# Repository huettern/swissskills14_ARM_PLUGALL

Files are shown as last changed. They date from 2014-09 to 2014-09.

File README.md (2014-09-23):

swissskills14_ARM_PLUGALL
=========================

I participated to the Swiss Skills 2014. One task was to design specific software. I prepared myself with a custom microcontroller board and some libraries for faster workflow. 
I'm sharing my sources here for others to have some open libraries for the STM32f3 family. The code is not very good commented, so if you have questions or troubles, feel free to contact me.

Directory Hardware
------------------

This directory contains the Altium project and manufature data for the PLUGALL ARM board.

Directory Software
------------------

This directory contains the template code and my self-written libraries to handle the PLUGALL bus communication.

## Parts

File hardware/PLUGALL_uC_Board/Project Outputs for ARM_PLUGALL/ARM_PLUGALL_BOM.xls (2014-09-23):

Comment | Designator | Quantity | Value | Footprint | MM Pnum
C | C1, C2, C5, C7, C8, C11, C12, C13, C14, C15, C16 | 11 | 100nF | 0805
C | C3, C4, C9 | 3 | 10uF | 0805
C | C6, C10 | 2 | 1uF | 0805
LED | D1 | 1 | BLU | D_0603
LED | D4 | 1 | GRN | D_0603
LED | D5 | 1 | RED | D_0603
R | R1, R4 | 2 | 4k7 | R_0603
R | R2, R5, R6, R7, R8, R9, R10, R11, R12, R13, R14, R15, R16 | 13 | 1k | R_0603
R | R3, R18, R19 | 3 | 100 | R_0603
SW | S1 | 1 | SW | SW_4x4x1.5
STM32F373RBT6 | U1 | 1 | STM32F372RBT6 | STM-LQFP64_V
74LVX3245 | U2, U3 | 2 | 74LVX3245 | TSSOP24
LM3940IMP-3.3 | U4 | 1 | LM3940IMP-3.3 | SOT-223
V_REF | U5 | 1 | LM4050 | SOT-23
SN74LV1T34 | U6, U7, U8 | 3 | SN74LV1T34 | DCK
FDV301N | V1, V2 | 2 | FDV301N | SOT-23
PLUGALL_Bus_Con | X1 | 1 | 2x14 | CON14X2
Socket_2mm | X2, X4 | 2 | Banana_2mm_RED | 2MM_BANANA
Socket_2mm | X3, X5 | 2 | Banana_2mm_BLK | 2MM_BANANA
Header 5H | X6 | 1 | 1X5 | HDR1X5H
SWD | X7 | 1 | 2X5 | 4448.0054
 |  | 55

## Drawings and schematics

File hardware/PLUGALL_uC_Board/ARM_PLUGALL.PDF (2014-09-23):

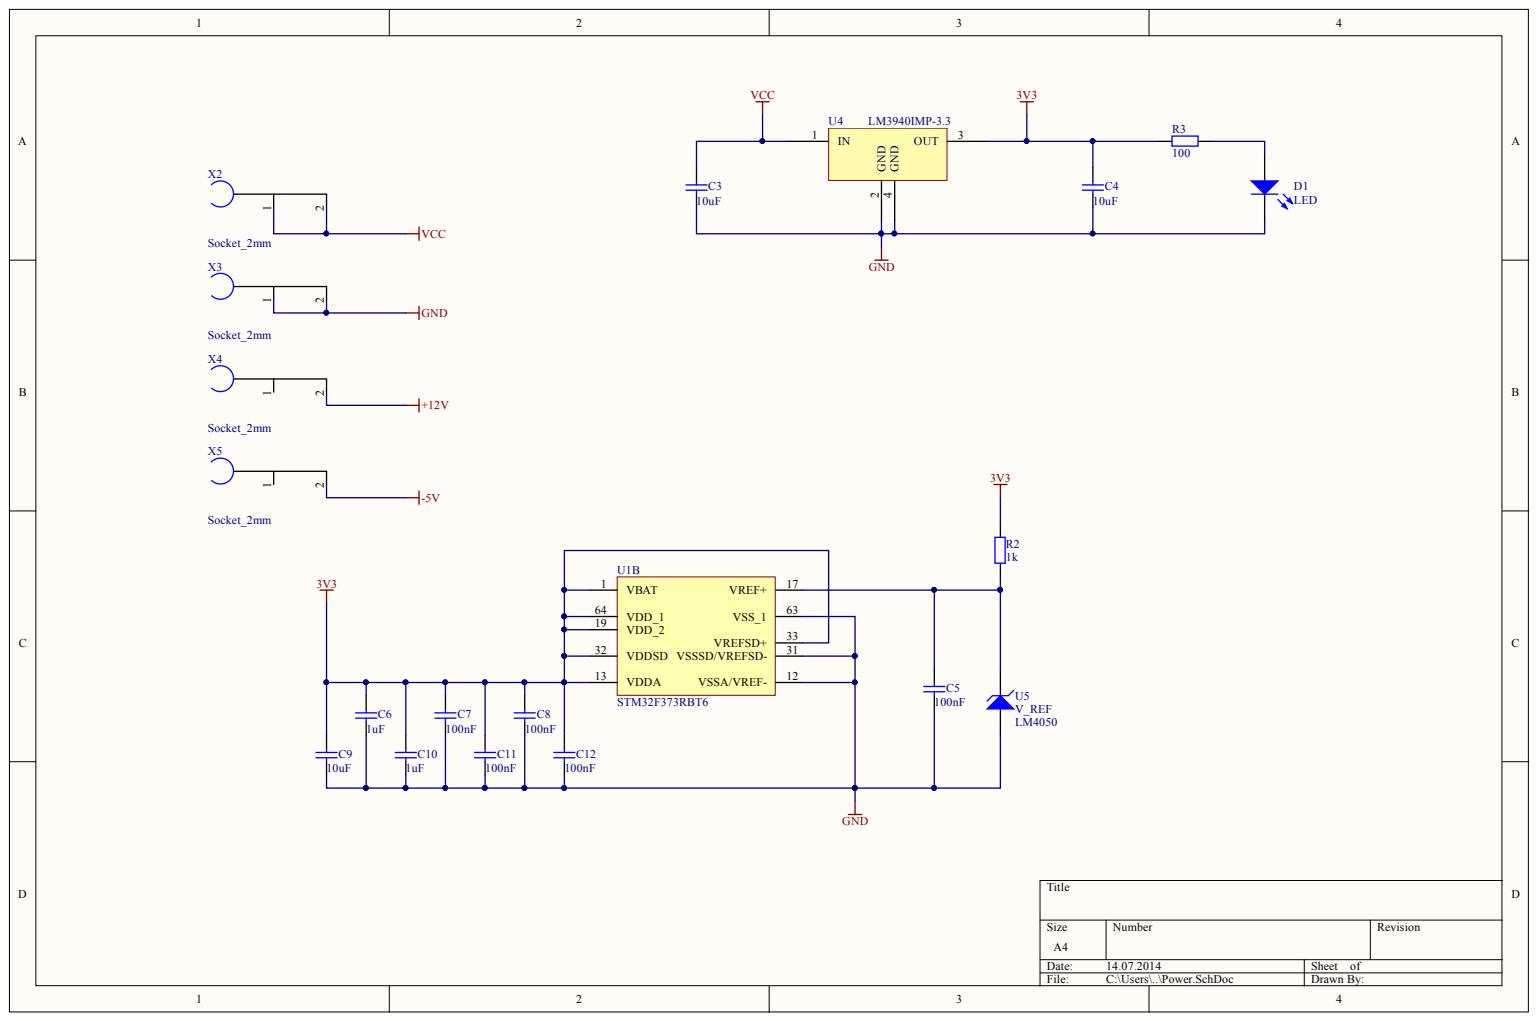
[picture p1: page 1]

6 4 | 6 3
1 9 | 3 3

3 2 | V D DSD VSSSD / VREFSD -V D D A VSSA / VREF- | 3 1

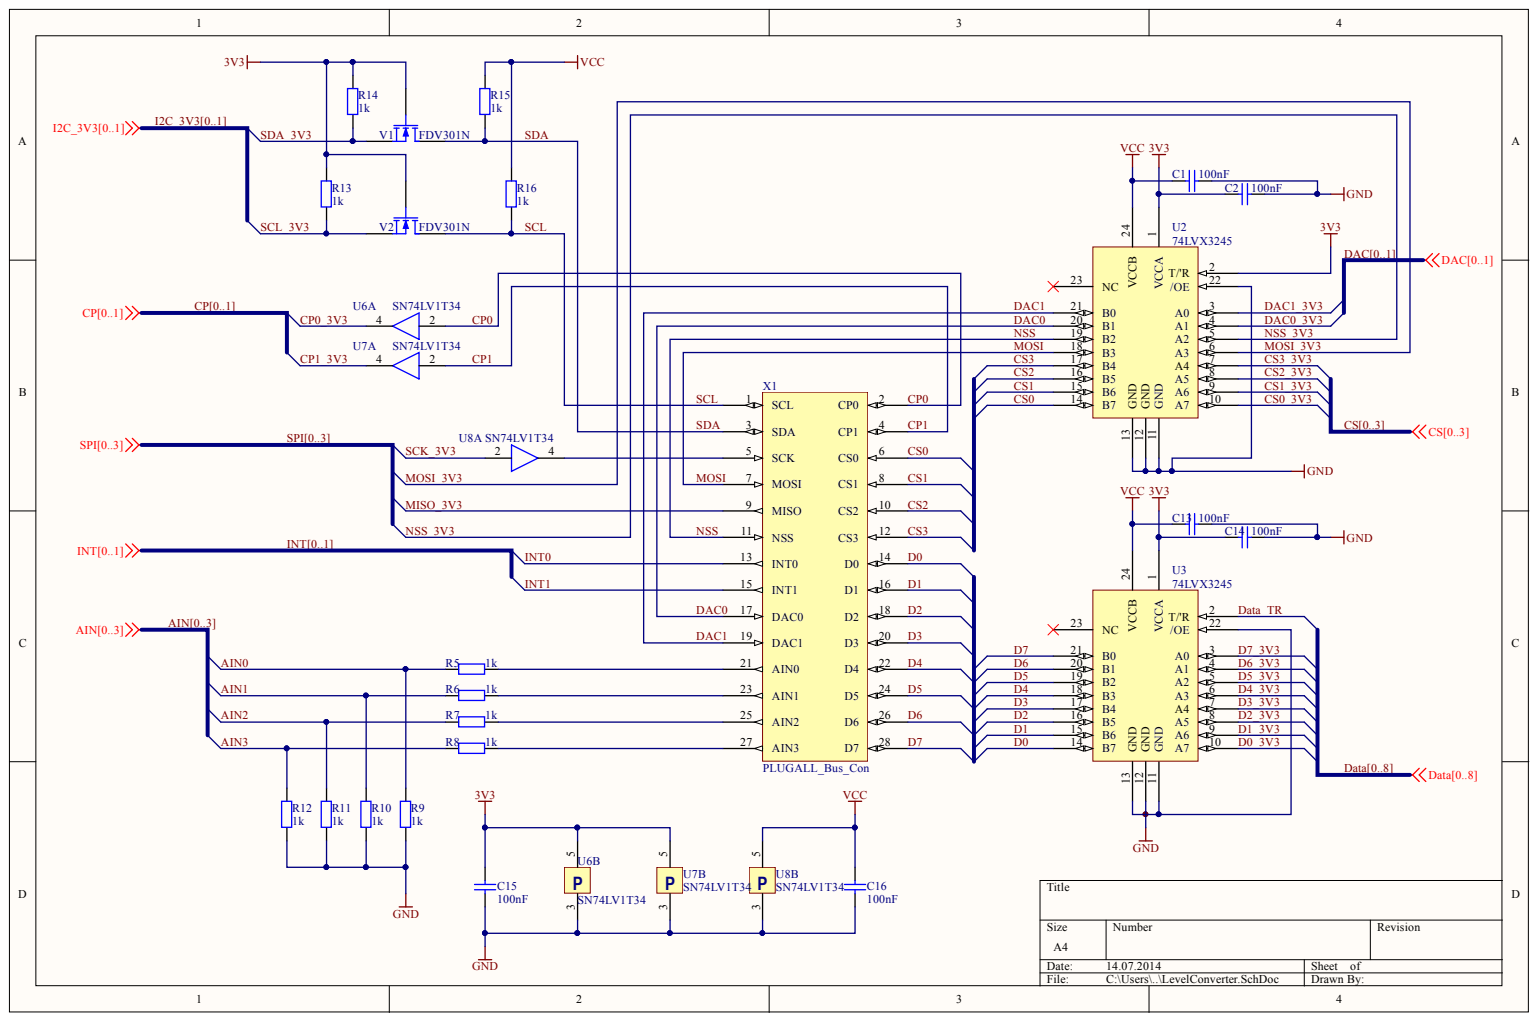
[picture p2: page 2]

MOSI NSS DAC0 DAC1 1 1 | 1 2 CS3

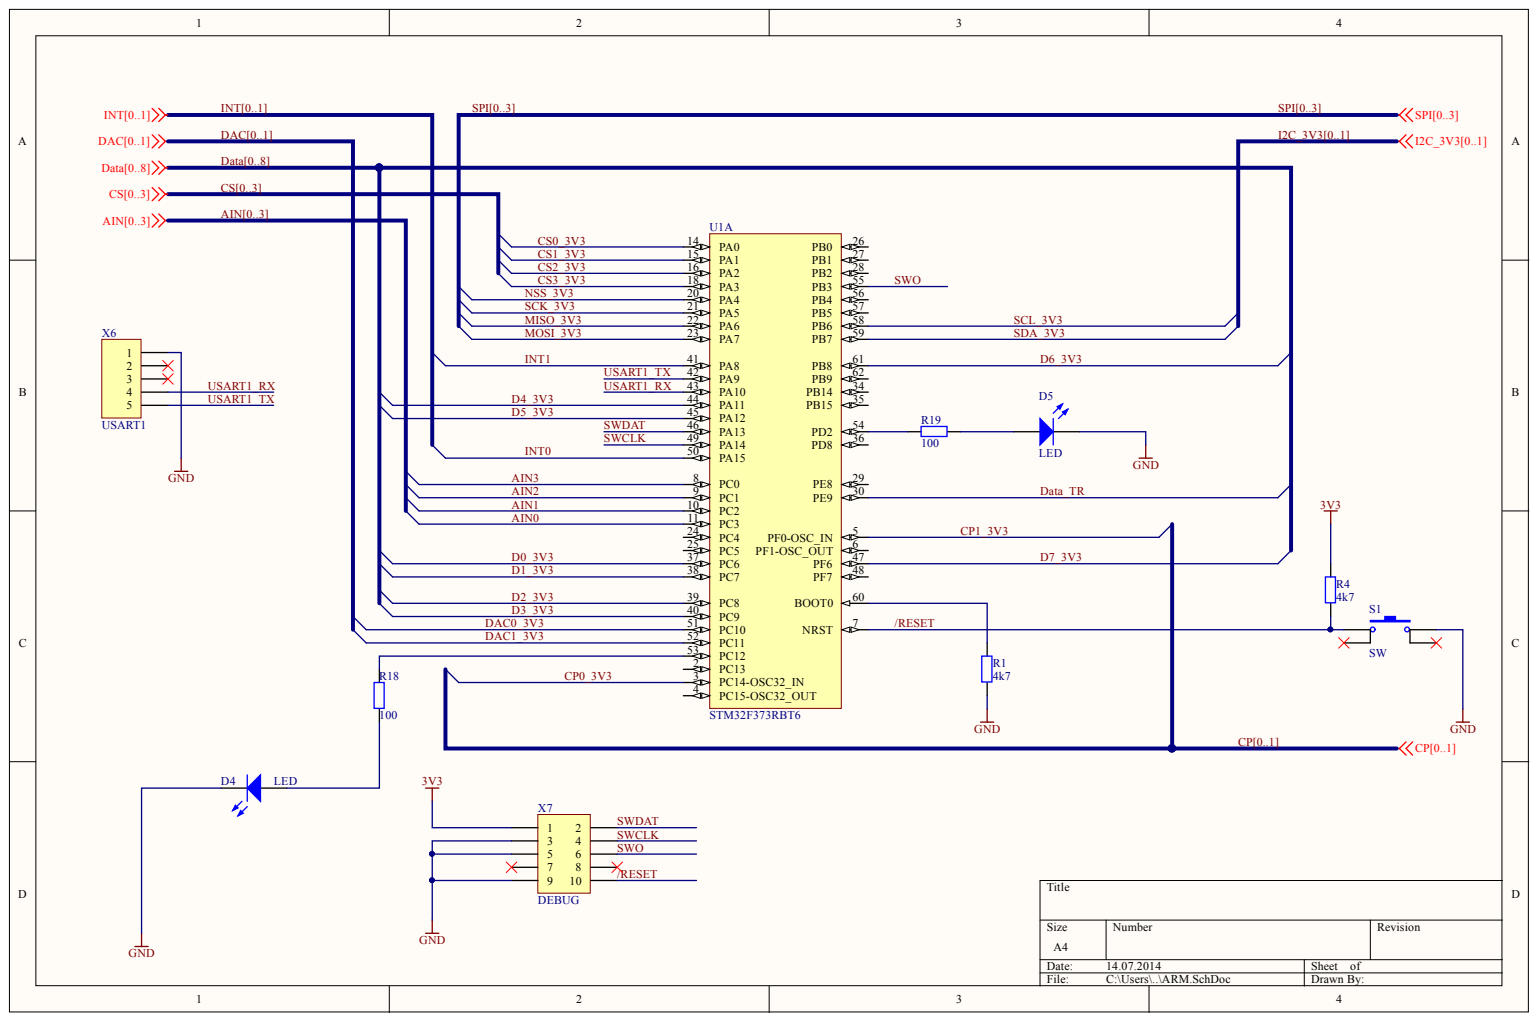
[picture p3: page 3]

AIN[0..3 ]

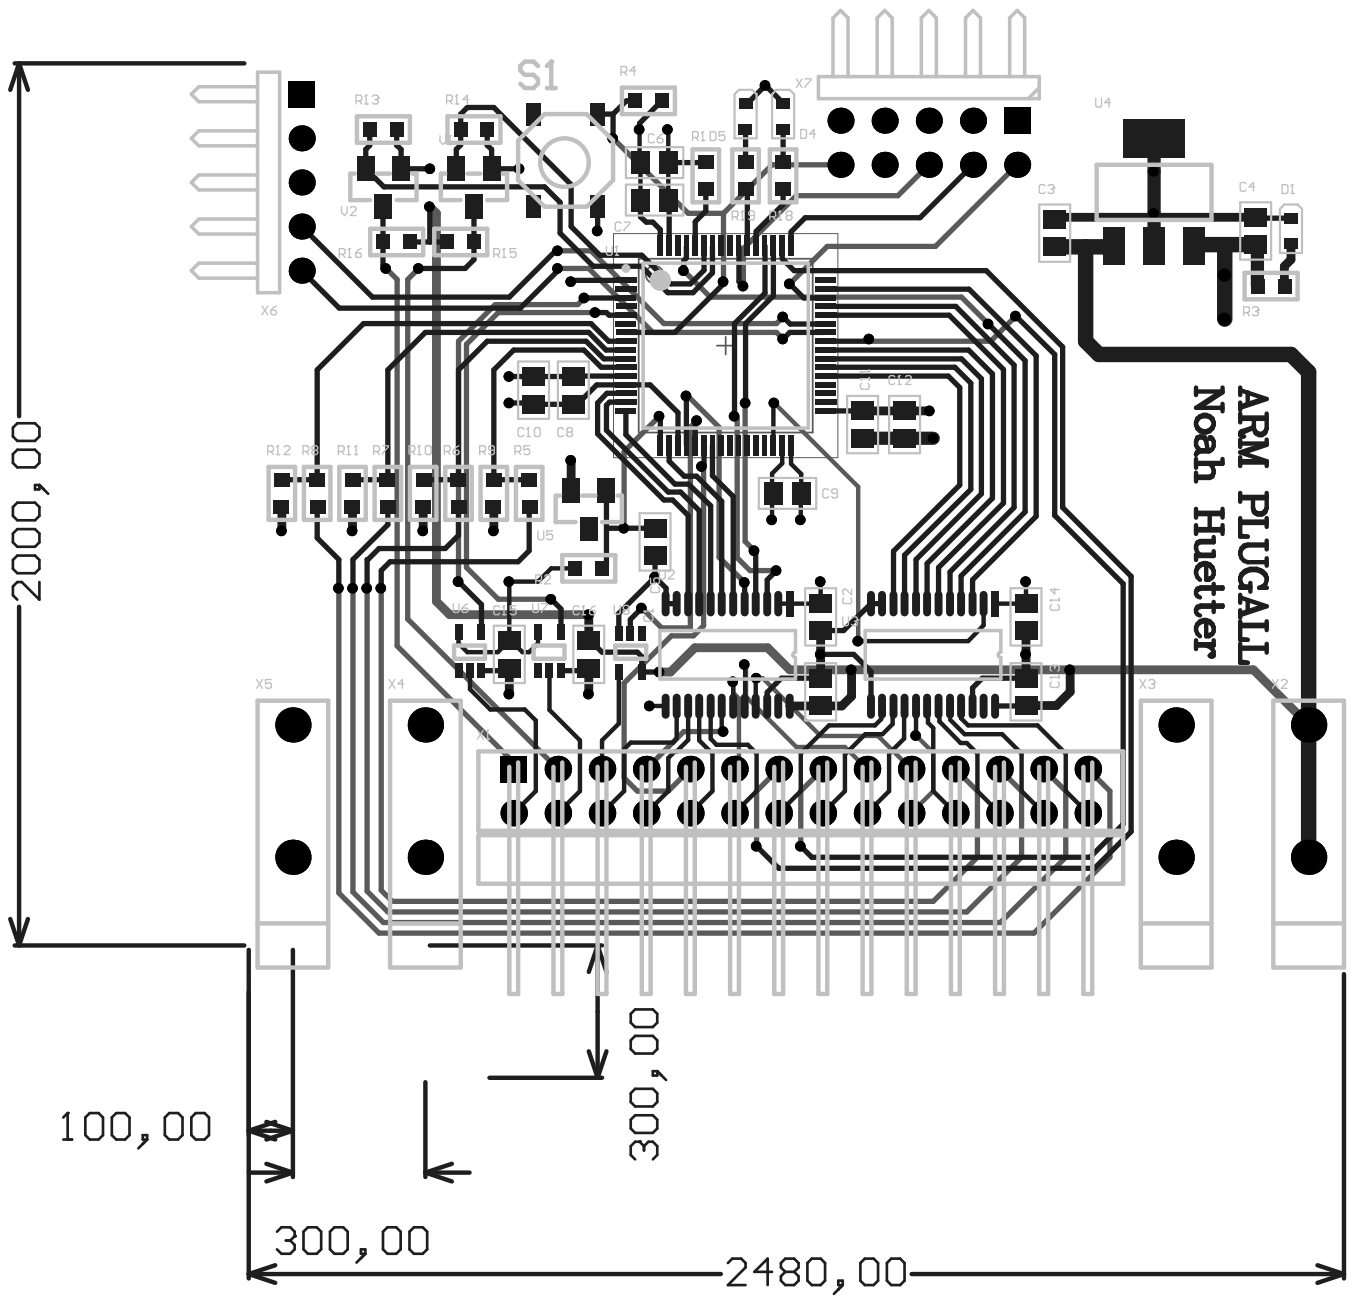
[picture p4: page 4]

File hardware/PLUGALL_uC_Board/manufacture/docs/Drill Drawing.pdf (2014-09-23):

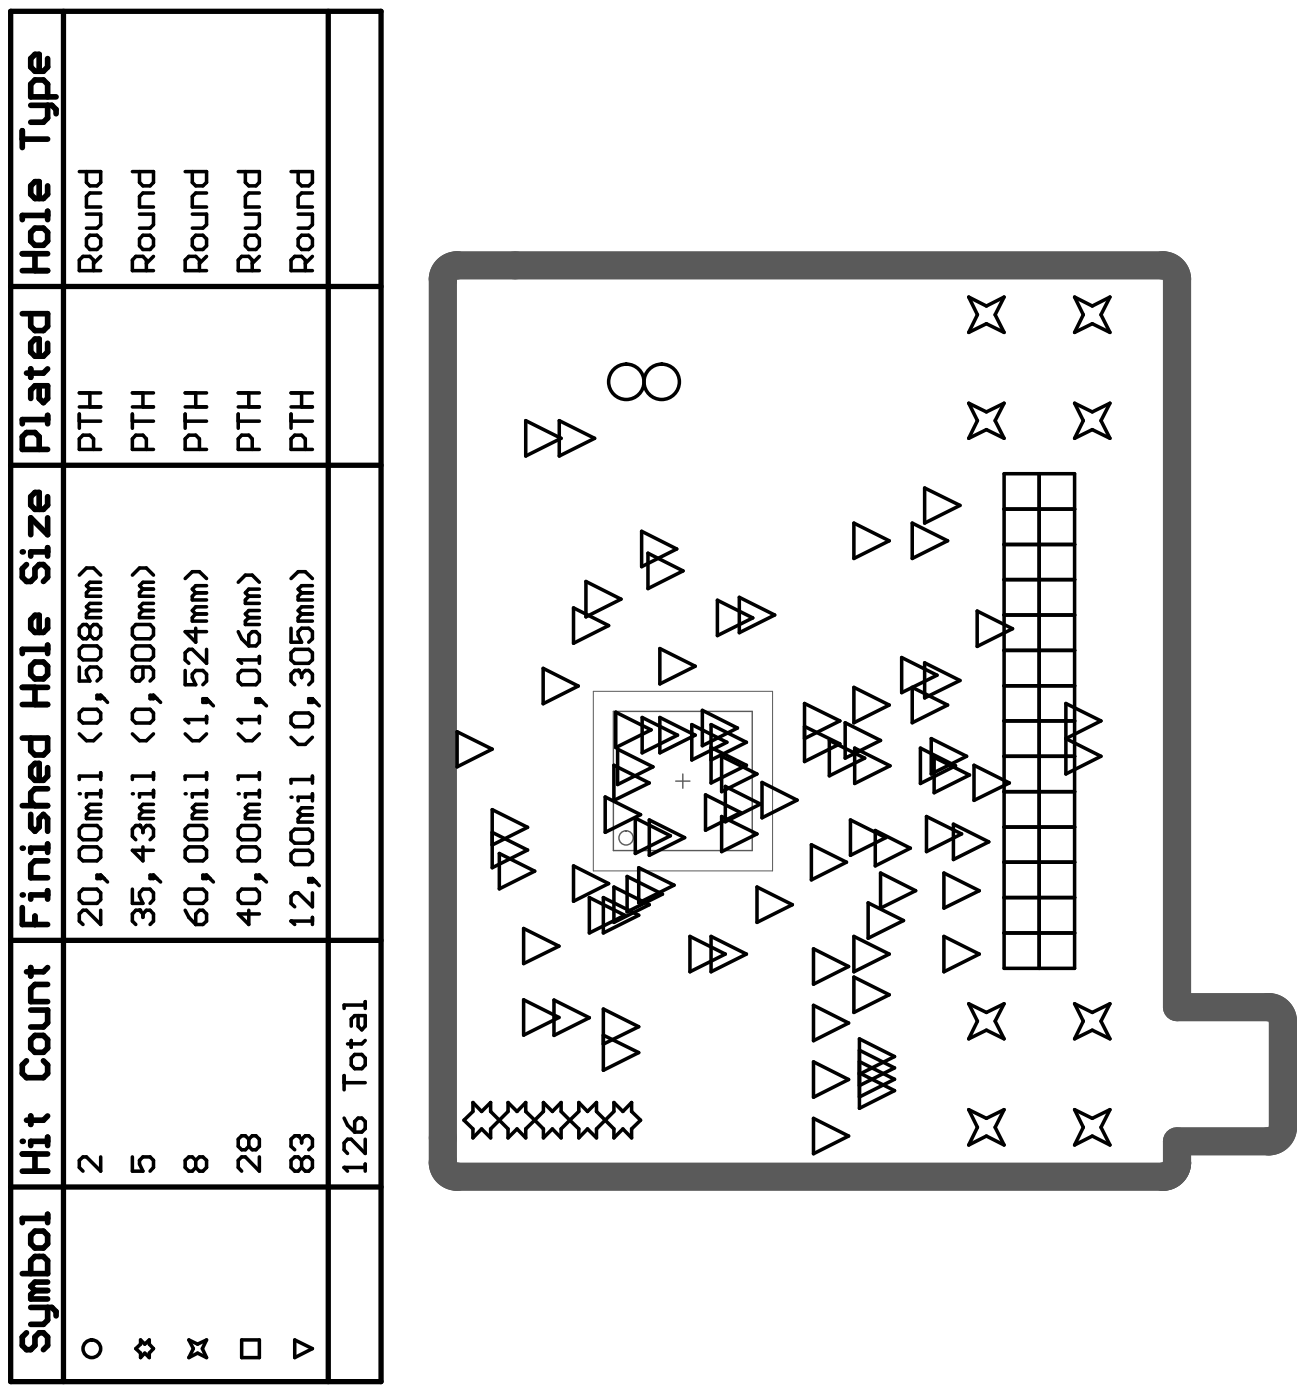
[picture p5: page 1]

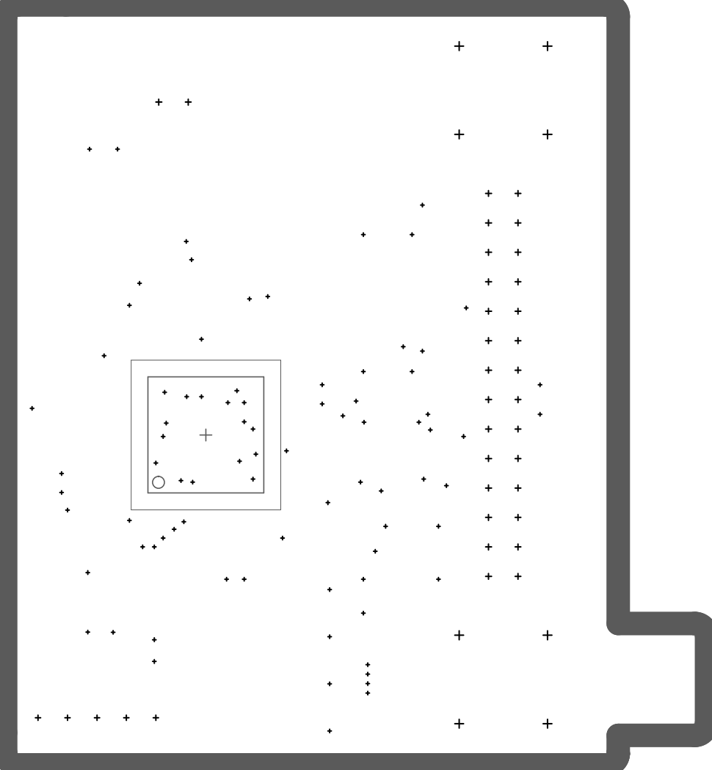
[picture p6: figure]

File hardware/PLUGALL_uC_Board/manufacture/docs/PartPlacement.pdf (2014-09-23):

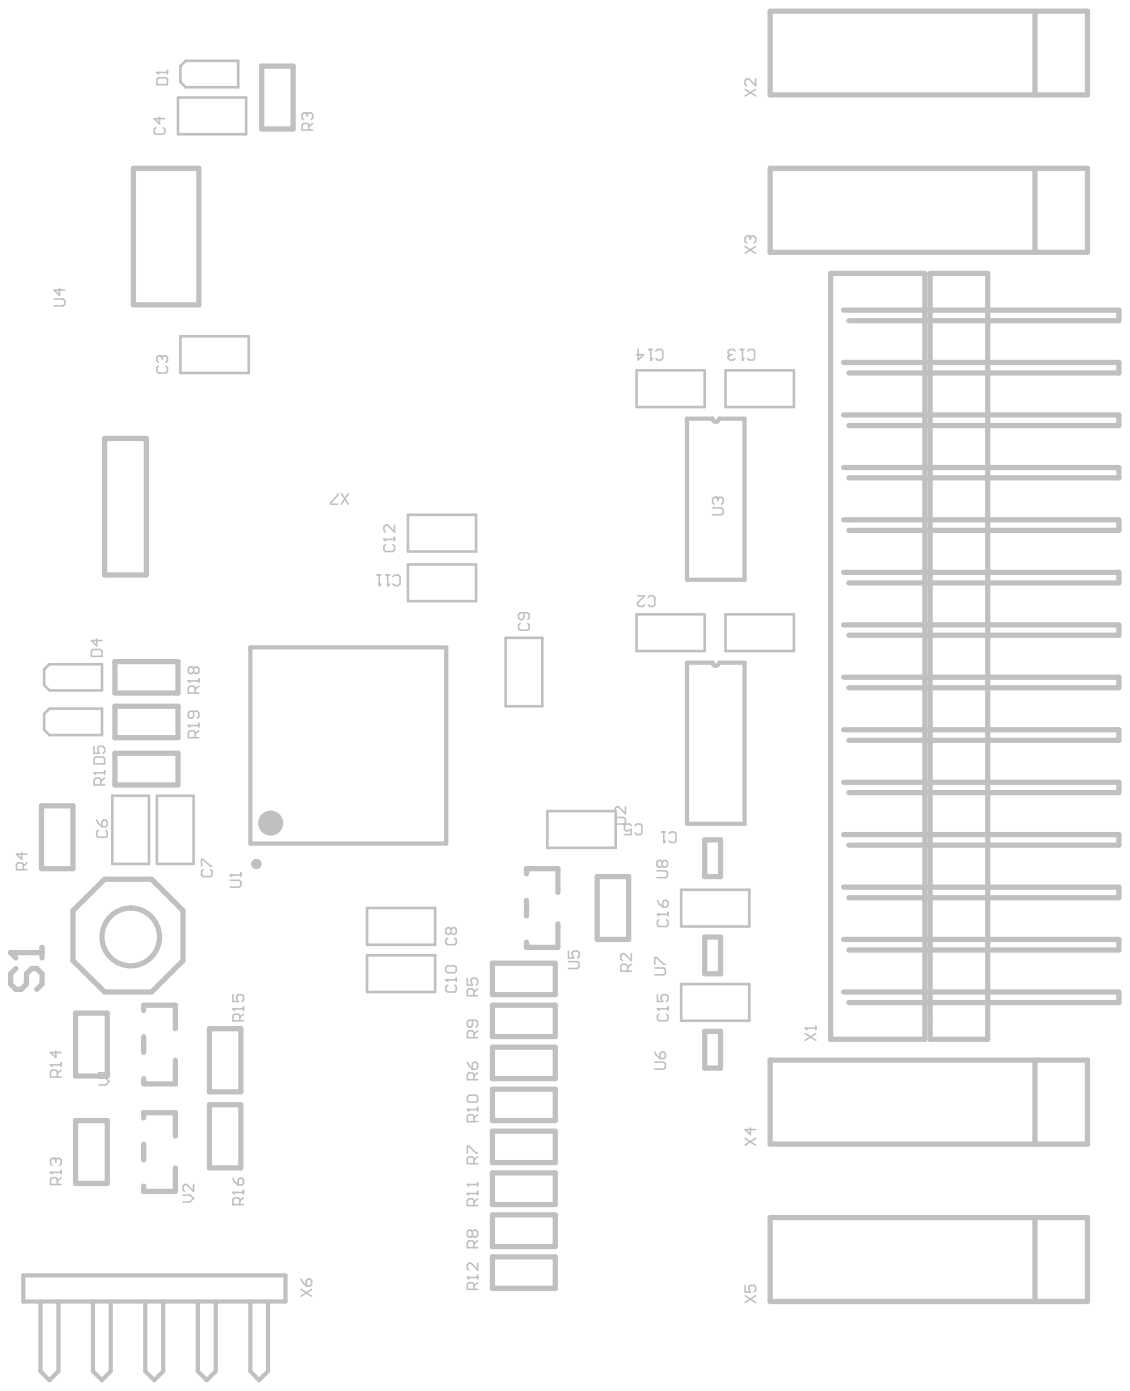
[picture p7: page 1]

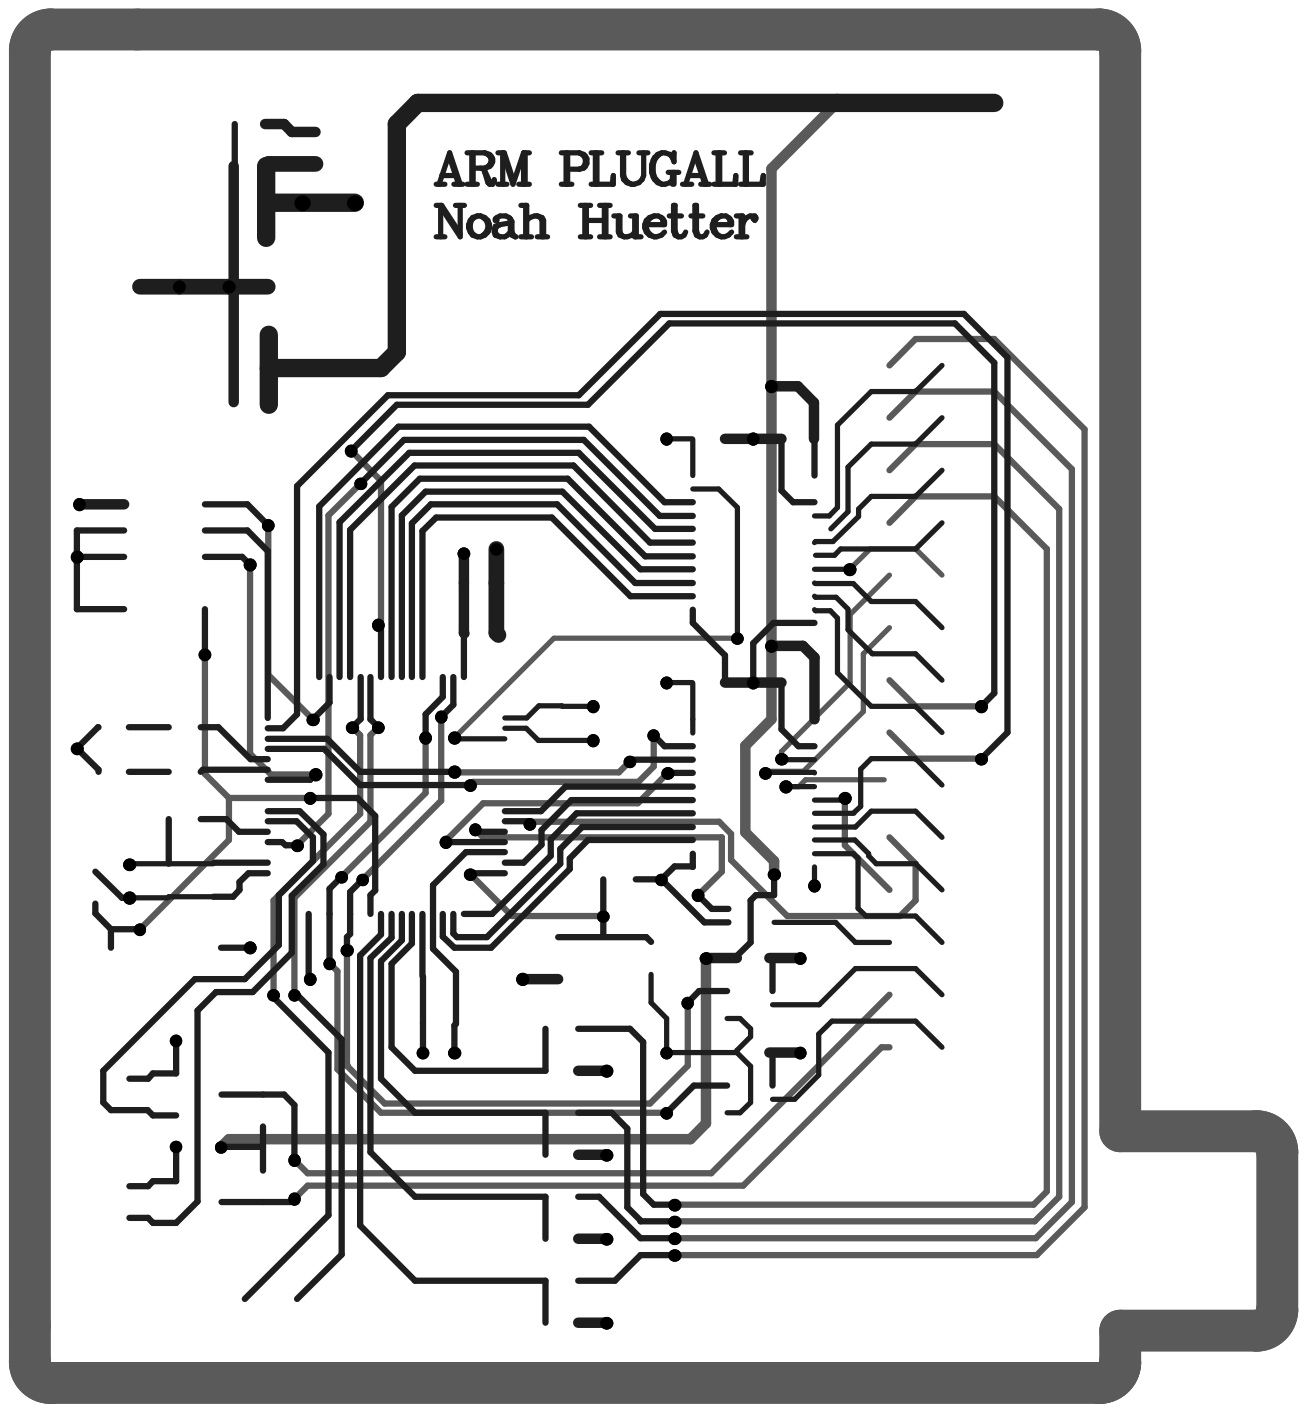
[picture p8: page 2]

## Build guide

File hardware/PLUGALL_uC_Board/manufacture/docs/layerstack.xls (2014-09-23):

Board Stack Report
Stack Up |  |  | Layer Stack
Layer | Board Layer Stack | Board Layer Stack | Name | Material | Thickness | Constant
1 |  |  | Top Paste
2 |  |  | Top Overlay
3 |  |  | Top Solder | Solder Resist | 0,40mil | 3,5
4 |  |  | Top Layer | Copper | 1,40mil
5 |  |  | Dielectric 1 | FR-4 | 10,00mil | 4,2
6 |  |  | GND | Copper | 1,42mil
7 |  |  | Dielectric 2 |  | 10,00mil | 4,2
8 |  |  | VCC | Copper | 1,42mil
9 |  |  | Dielectric 3 |  | 10,00mil | 4,2
10 |  |  | Bottom Layer | Copper | 1,40mil
11 |  |  | Bottom Solder | Solder Resist | 0,40mil | 3,5
12 |  |  | Bottom Overlay
13 |  |  | Bottom Paste
 | Height : 36,43mil | Height : 36,43mil

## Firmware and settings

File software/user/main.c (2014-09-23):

/*****************************************************************************
* Project:            
* Target:             STM32F372RBT6
* Type:               Main-module
* Description:        main
* Compiler:           ANSI-C
* Filename:           main.c
* Version:            1.0
* Author:             Noah Huetter
* Creation-Date:      07.08.14
******************************************************************************
* Modification History:
* 
* [1.0]     07.08.14   NHU   first release
*
*****************************************************************************/  
#include "stm32f37x_conf.h"
#include "plugall.h"
#include "dac.h"
#include "spi.h"
#include "i2c.h"
#include "adc.h"
#include "int.h"
#include "shell.h"
#include "LCD.h"
#include "delay.h"

#include <stdio.h>
#include <stdlib.h>

/*****************************************************************************
* Defines and Makros
*****************************************************************************/  

/*****************************************************************************
* Private Data
*****************************************************************************/   

RCC_ClocksTypeDef RCC_Clocks;

unsigned int m_MSCounter = 0;
	
/*****************************************************************************
* Private Function Declaration
*****************************************************************************/ 
void fInit (void);

void cbGPTimeOut (void);
void cbGPTimeOut1 (void);
void cbGPTimeOut2 (void);
void cbGPTimeOut3 (void);
void cbGPTimeOut4 (void);

/*****************************************************************************
* MAIN ROUTINE
*****************************************************************************/ 
int main (void)
{	
	RCC_GetClocksFreq(&RCC_Clocks);
	
	fInit(); //Running at 64MHz
	
	for(;;)
	{
		/* PLACE YOUR CODE HERE */
		
		
		
		
		
		/* Periodic Handler */
		SHELL_HandleTx();
		SHELL_LineParser();
		DLY_fHandleTasks();
		PLG_fHandleEvents();
	}
	
}
	
/*****************************************************************************
* Private Functions
*****************************************************************************/ 
/*=======================================================================*//**
  @brief Inits peripherals
*//*========================================================================*/
void fInit (void)
{
	SHELL_fInit();
	DLY_fInit();
	
	LED_YEL_OFF();
	LED_RED_OFF();

	SHELL_fClearTerminal();
	printf("ARM PLUGALL v1 Started!                                   Copyright Noah Huetter\r\n\r\n");
	printf("SYSCLK=%dMHz HCLK=%dMHz \r\n",RCC_Clocks.SYSCLK_Frequency / 1000000, RCC_Clocks.HCLK_Frequency / 1000000);
	SHELL_fDrawLineOfChar('*');
	SHELL_fEchoControl(ECHO_ON);
	
	PLG_fInit();
	PLG_StartBusControl();
	
	DAC_fInit();
	SPI_fInit();
	I2C_fInit();
	I2C_fInitTempSensor();
	ADC_fInit();		
	INT_fInit();
	LCD_fInit();

	SysTick_Config(RCC_Clocks.HCLK_Frequency / 1000); //@1ms
	
	//DLY_fAddTimerTick(DLY_CONTINUOUS, 100, cbGPTimeOut);
	//DLY_fAddTimerTick(DLY_SINGLE_SHOT, 5000, cbGPTimeOut1);
	//DLY_fAddTimerTick(DLY_SINGLE_SHOT, 10000, cbGPTimeOut2);
	//DLY_fAddTimerTick(DLY_CONTINUOUS, 100, cbGPTimeOut3);
	//DLY_fAddTimerTick(DLY_CONTINUOUS, 100, cbGPTimeOut4);
	
	//PLG_SubscribeLongPressHandler(PLG_CLAV_STOP_LONGPRESS, 	1000, cbGPTimeOut1);
	//PLG_SubscribeLongPressHandler(PLG_CLAV_ENTER_LONGPRESS, 2000, cbGPTimeOut2);
	//PLG_SubscribeLongPressHandler(PLG_CLAV_DOWN_LONGPRESS, 	 100, cbGPTimeOut3);
	//PLG_SubscribeLongPressHandler(PLG_CLAV_UP_LONGPRESS, 	  5000, cbGPTimeOut4);
}	
	
/*=======================================================================*//**
  @brief Sys Tick Interrupt called every 1ms
*//*========================================================================*/
void SysTick_Handler (void)
{
	PLG_fHandleBus();
	m_MSCounter++;
}

/*=======================================================================*//**
  @brief General Purpose Callback 100ms
*//*========================================================================*/
void cbGPTimeOut (void)
{
	
	
}


/*=======================================================================*//**
  @brief General Purpose Callback
*//*========================================================================*/
void cbGPTimeOut1 (void)
{
	
}


/*=======================================================================*//**
  @brief General Purpose Callback
*//*========================================================================*/
void cbGPTimeOut2 (void)
{
	
}


/*=======================================================================*//**
  @brief General Purpose Callback
*//*========================================================================*/
void cbGPTimeOut3 (void)
{
	
}


/*=======================================================================*//**
  @brief General Purpose Callback
*//*========================================================================*/
void cbGPTimeOut4 (void)
{	
	
}


#ifdef  USE_FULL_ASSERT
void assert_failed(uint8_t* file, uint32_t line)
	{ 
	while (1){}
	}
#endif

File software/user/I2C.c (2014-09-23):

/*****************************************************************************
* Project:            PLUGALL
* Target:             
* Type:               I2C controlls
* Version:            1.0
* Author:             Noah Huetter
* Creation-Date:      07.2014
******************************************************************************
* Modification History:
* 
* [1.0]     07.2014   NHU   first release
*
*****************************************************************************/  
#include "stm32f37x_conf.h"
#include "I2C.h"
#include "shell.h"

#include <stdio.h>

#define MAX_DATA_BYTES 64

#define I2C_SCL_LOW_PULSE		5000 //[ns]
#define I2C_SCL_HIGH_PULSE	5000//[ns]

#define I2C_SDA_SETUP_TIME  250 //[ns]
#define I2C_SDA_HOLD_TIME   250 //[ns]

#define I2C_PRESC	0x70000000	//0x0..0xf

#define TPRESC	125 //[ns]


/*****************************************************************************
* Private Data
*****************************************************************************/   
typedef struct {
	uint8_t address;
	uint8_t data[MAX_DATA_BYTES];
	uint8_t nbytes;
	uint8_t nbytes_left;
	uint8_t* read_reg;
} SlaveStruct;

SlaveStruct m_slave;

uint8_t m_TransmissionRuning = 0;


/*****************************************************************************
* Private Functions Prototypes
*****************************************************************************/ 



/*****************************************************************************
* Private Functions 
*****************************************************************************/ 


/*****************************************************************************
* Public Functions 
*****************************************************************************/ 
/*=======================================================================*//**
  @brief Init function
*//*========================================================================*/
void I2C_fInit (void)
{
	static I2C_InitTypeDef   				I2C_InitStruct;
	static NVIC_InitTypeDef					NVIC_InitStruct;
	
	uint32_t timing_temp_reg;
	
	GPIO_PinAFConfig(GPIOB, GPIO_PinSource6, GPIO_AF_4);
	GPIO_PinAFConfig(GPIOB, GPIO_PinSource7, GPIO_AF_4);
	
	RCC_I2CCLKConfig(RCC_I2C1CLK_SYSCLK); //Sysclock -> 64MHz 
	
	
	
	
	
	timing_temp_reg = ( ( (I2C_PRESC) ) | 	//PRESCALER
											( ( (I2C_SDA_SETUP_TIME / TPRESC ) -1 ) << 20 ) | 	//SDA Setup Time
											( (I2C_SDA_HOLD_TIME / TPRESC ) << 16 ) | 	//SDA Hold Time
											( ( (I2C_SCL_HIGH_PULSE / TPRESC ) -1 ) <<  8 ) | 	//SCL High Pulse
											( ( (I2C_SCL_LOW_PULSE / TPRESC ) -1 ) <<  0 ) ); 	//SCL Low Pulse
	
	
	RCC_APB1PeriphClockCmd(RCC_APB1Periph_I2C1, ENABLE);

	NVIC_InitStruct.NVIC_IRQChannel = I2C1_EV_IRQn;	//I2C event interrupt
	NVIC_InitStruct.NVIC_IRQChannelPreemptionPriority =  10; //0 highest, 15 lowest
	NVIC_InitStruct.NVIC_IRQChannelSubPriority = 0;	//dont care
	NVIC_InitStruct.NVIC_IRQChannelCmd = ENABLE;
	NVIC_Init(&NVIC_InitStruct);
	
	NVIC_InitStruct.NVIC_IRQChannel = I2C1_ER_IRQn;	//I2C error interrupt
	NVIC_InitStruct.NVIC_IRQChannelPreemptionPriority =  10; //0 highest, 15 lowest
	NVIC_InitStruct.NVIC_IRQChannelSubPriority = 0;	//dont care
	NVIC_InitStruct.NVIC_IRQChannelCmd = ENABLE;
	NVIC_Init(&NVIC_InitStruct);
	
  I2C_InitStruct.I2C_Mode = I2C_Mode_I2C;  
  I2C_InitStruct.I2C_AnalogFilter = I2C_AnalogFilter_Enable;
  I2C_InitStruct.I2C_DigitalFilter = 0x00;
  I2C_InitStruct.I2C_Ack = I2C_Ack_Enable;
  I2C_InitStruct.I2C_AcknowledgedAddress = I2C_AcknowledgedAddress_7bit;
  I2C_InitStruct.I2C_Timing = timing_temp_reg; //100kHz Clock: 0x00222727
	I2C_Init(I2C1, &I2C_InitStruct);
	
	
	I2C_Cmd(I2C1, ENABLE);
	
	//I2C_ITConfig(I2C1, I2C_IT_TCI, ENABLE);	//transfer complete
	I2C_ITConfig(I2C1, I2C_IT_TXI, ENABLE);	//Transmit buffer interrupt status
	I2C_ITConfig(I2C1, I2C_IT_NACKF, ENABLE);	//Not acknowledge
	I2C_ITConfig(I2C1, I2C_IT_RXI, ENABLE);	//receiver full
	
	
}


/*=======================================================================*//**
  @brief Inits DS1621 temperature sensor
*//*========================================================================*/
void I2C_fInitTempSensor (void)
{
	static uint8_t data[5];
	static uint32_t delay;
	
	data[0] = 0xAC; //command: Access config
	data[1] = 0x02;	//data: Output is active High, continuous mode
	
	delay = 1;
	while(I2C_fGetTransmissionComplete() && ++delay){};
	if(delay == 0)
	{
		printf("I2C tr complete timeout");
		return;	//waited too long
	}
	I2C_fSendBytes(0x90, data, 2);
		
	data[0] = 0xA1; //command: Access TH - High temp treshold
	data[1] = 30;	//data: MSB - 30.0 C
	data[1] = 0;	//data: LSB
	
	delay = 1;
	while(I2C_fGetTransmissionComplete() && ++delay){};
	if(delay == 0)
	{
		printf("I2C tr complete timeout");
		return;	//waited too long
	}
	I2C_fSendBytes(0x90, data, 3);
		
	data[0] = 0xA2; //command: Access TL - Low temp treshold
	data[1] = 18;	//data: MSB - 18.0 C
	data[1] = 0;	//data: LSB
	
	delay = 1;
	while(I2C_fGetTransmissionComplete() && ++delay){};
	if(delay == 0)
	{
		printf("I2C tr complete timeout");
		return;	//waited too long
	}
	I2C_fSendBytes(0x90, data, 3);
		
	data[0] = 0xEE; //command: Start conversion
	
	delay = 1;
	while(I2C_fGetTransmissionComplete() && ++delay){};
	if(delay == 0)
	{
		printf("I2C tr complete timeout");
		return;	//waited too long
	}
	I2C_fSendBytes(0x90, data, 1);
	
}


/*=======================================================================*//**
  @brief 
*//*========================================================================*/
void I2C_fSendBytes (uint8_t addr, uint8_t* data, uint8_t bytes)
{
	uint8_t ctr;
	
	if (m_TransmissionRuning == 1) return;
	m_TransmissionRuning = 1;
	
	//save transmission data
	m_slave.address = addr;
	m_slave.nbytes = bytes;
	m_slave.nbytes_left = bytes;
	
	for(ctr = 0; ctr < bytes; ctr++)
	{
		m_slave.data[ctr] = data[ctr];
	}
	
	//start transmission
	I2C_TransferHandling(I2C1, m_slave.address = addr, m_slave.nbytes, 
											I2C_AutoEnd_Mode, I2C_Generate_Start_Write);	//write
}
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
